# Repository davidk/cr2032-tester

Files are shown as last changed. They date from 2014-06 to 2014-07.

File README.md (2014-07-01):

# CR2032 Battery Tester

Test your CR2032 coin cells using this breakout. Below 2.64v, the LED ceases to
light, indicating that the coin cell is nearing the end of its useful life.

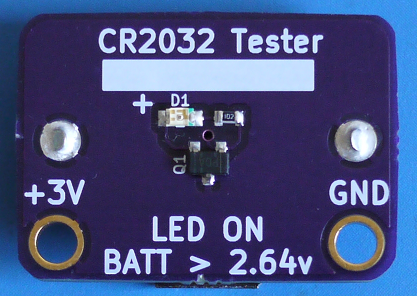
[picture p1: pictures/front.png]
CR2032 battery tester


## Bill of Materials

This builds 1 board. You'll get at least 3 from OSHPark.

| Quantity | Description | Digikey/Mouser Part Number | Board Placement |
| --- | --- | --- | --- |
| 1 | TPS3809L30DBVR | [296-10917-1-ND](http://www.digikey.com/product-detail/en/TPS3809L30DBVR/296-10917-1-ND) / [595-TPS3809L30DBVR](http://www.mouser.com/access/?pn=595-TPS3809L30DBVR) | Q1 |
| 1 | 20mm coin cell holder (through-hole) | [3003K-ND](http://www.digikey.com/product-detail/en/3003/3003K-ND) / [534-3003](http://www.mouser.com/access/?pn=534-3003) | Rear |
| 1 | 0603 imperial series resistor for LED | Generic value\*\* | R1 |
| 1 | 0805 imperial LED | Generic/Any type\*\*\* | D1 |

I used the following parts for these, but you should really source to your
desired quantity:

\*\* 1k 0603 resistor (from the spare parts bin, if you really want one though..
[RMCF0603JT1K00CT-ND](http://www.digikey.com/product-detail/en/RMCF0603JT1K00/RMCF0603JT1K00CT-ND).
Try another part and order a bunch for a better discount / price.)

\*\*\* Mouser
[645-598-8130-107F](http://www.mouser.com/access/?pn=645-598-8130-107F) (Orange
Dialight LED, Vf=1.7V, If=20mA)

## Fabrication

[OSHPark shared project here](https://oshpark.com/shared_projects/Qcq4ZSKX)

## License

Creative Commons CC0 1.0 Universal

## Trivia

This board is actually a mashup of Chris Gammell's and Dave Jones' projects. The
coin cell holder and layout comes from the free Getting to Blinky KiCAD
tutorial. The TI part and usage is derived from Dave Jones' µCurrent.  

The - battery contact area was inspired by Adafruit's Ultimate GPS Breakout (leaving the
purple soldermask causes the copper ENIG contact area to be in-set, preventing
an inserted battery from making proper contact).

#### Power usage

With a 1k series resistor and 0805 LED, this board uses approximately 1mA if the battery is left inserted with the LED on. Below the IC's threshold, everything takes up 9µA without the LED lit.

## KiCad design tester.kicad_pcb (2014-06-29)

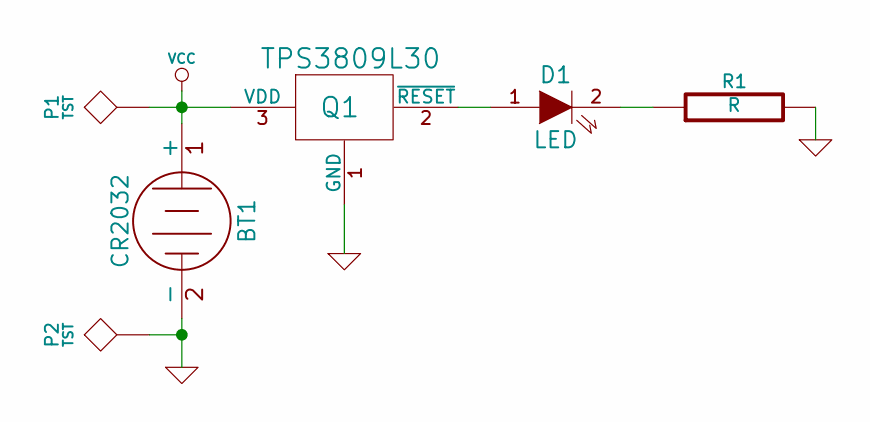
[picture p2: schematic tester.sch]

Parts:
BT1: CR2032
D1: LED
P1, P2: TST
Q1: TPS3809L30
R1: R

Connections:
GND: BT1.2 (-), P2.1, Q1.1 (GND), R1.2
unnamed: D1.2 (K), R1.1
unnamed: D1.1 (A), Q1.2 (~RESET)
VCC: BT1.1 (+), P1.1, Q1.3 (VDD)

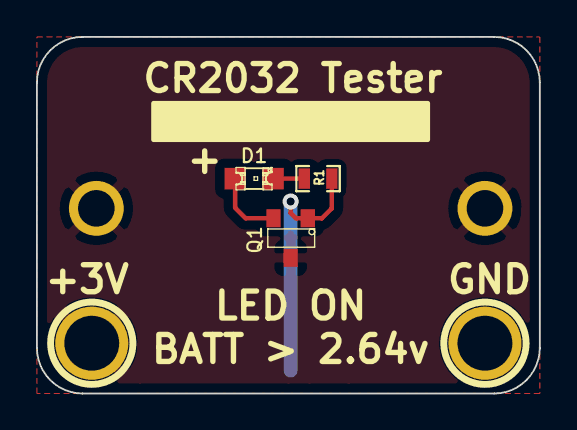
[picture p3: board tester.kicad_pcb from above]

Board: 2 copper layers, 27.9 x 19.8 mm, 6 parts (1 on the bottom side), 4 nets.

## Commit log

2014-06-29 Add a basic gitignore for KiCad files
2014-06-29 Add board files and modules
    [tester.kicad_pcb, tester.sch]
2014-06-29 Add generated gerbers (setup for OSHPark)
    [tester-B_Cu.gbl, tester-B_Mask.gbs, tester-B_SilkS.gbo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]
2014-06-30 Battery copper contact design credit
2014-06-30 Add PCB photo
2014-07-01 Add power usage statistics
    Measured with a pre-gold µCurrent and Agilent U1272A DMM
